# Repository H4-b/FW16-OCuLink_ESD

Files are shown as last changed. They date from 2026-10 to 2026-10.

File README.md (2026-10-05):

# OCuLink 8i Expansion Board for the Framework 16

## The schematic
rev1.1

The schematic in itself is pretty simple. You only need to connect the TX and RX PCIe lanes to the correct pins of the OCuLink connector. And then add components such as the EEPROM that the Embedded Controller (EC) on the laptop reads to configure GPIO pins and bifurcation.

A pdf version of the schematic is available [here](./imgs/schematic.pdf).

### EEPROM
As for the EEPROM, I have decided to use the same one that Framework is using in their [Dual SSD reference design](https://github.com/FrameworkComputer/ExpansionBay/tree/main/Dual%20SSD%20Reference%20Design). The `BR24G32FVT-3GE2`. The chip is marked as not recommended for new design according to Mouser, but it still seems to be in stock, although it can easily be swapped with another if required.

The EEPROM's address pins are all connected to the ground as that is the address the EC expects and by default the write protection (WP) is disabled by being connected to GND to allow writing data to it.

### Fans
For the fans I had to go with an alternative FPC header, as the one Framework uses on their boards was not available anywhere. The connector I use is slightly smaller, but still makes the connection nevertheless and the fans do spin up. I have specifically went with the [`AFC05-S04FIA-00`](https://www.lcsc.com/product-detail/C561383.html) that is available on LCSC to use with JLCPCB's assembly.

## Firmware
The firmware file is generated using [Framework's Expansion Bay tool](https://github.com/FrameworkComputer/ExpansionBayConfigurationGenerator). More info on the specific file I have been using in my testing and how I flashed it *SOON*.

## The PCB layout
rev1.1

For the layout I have went with a 4-layer board and did manage to successfully stay within JLCPCB's fabrication limits. For the production runs I have done a 1.2mm ENIG board and used the JLC04121H-7628 stackup.

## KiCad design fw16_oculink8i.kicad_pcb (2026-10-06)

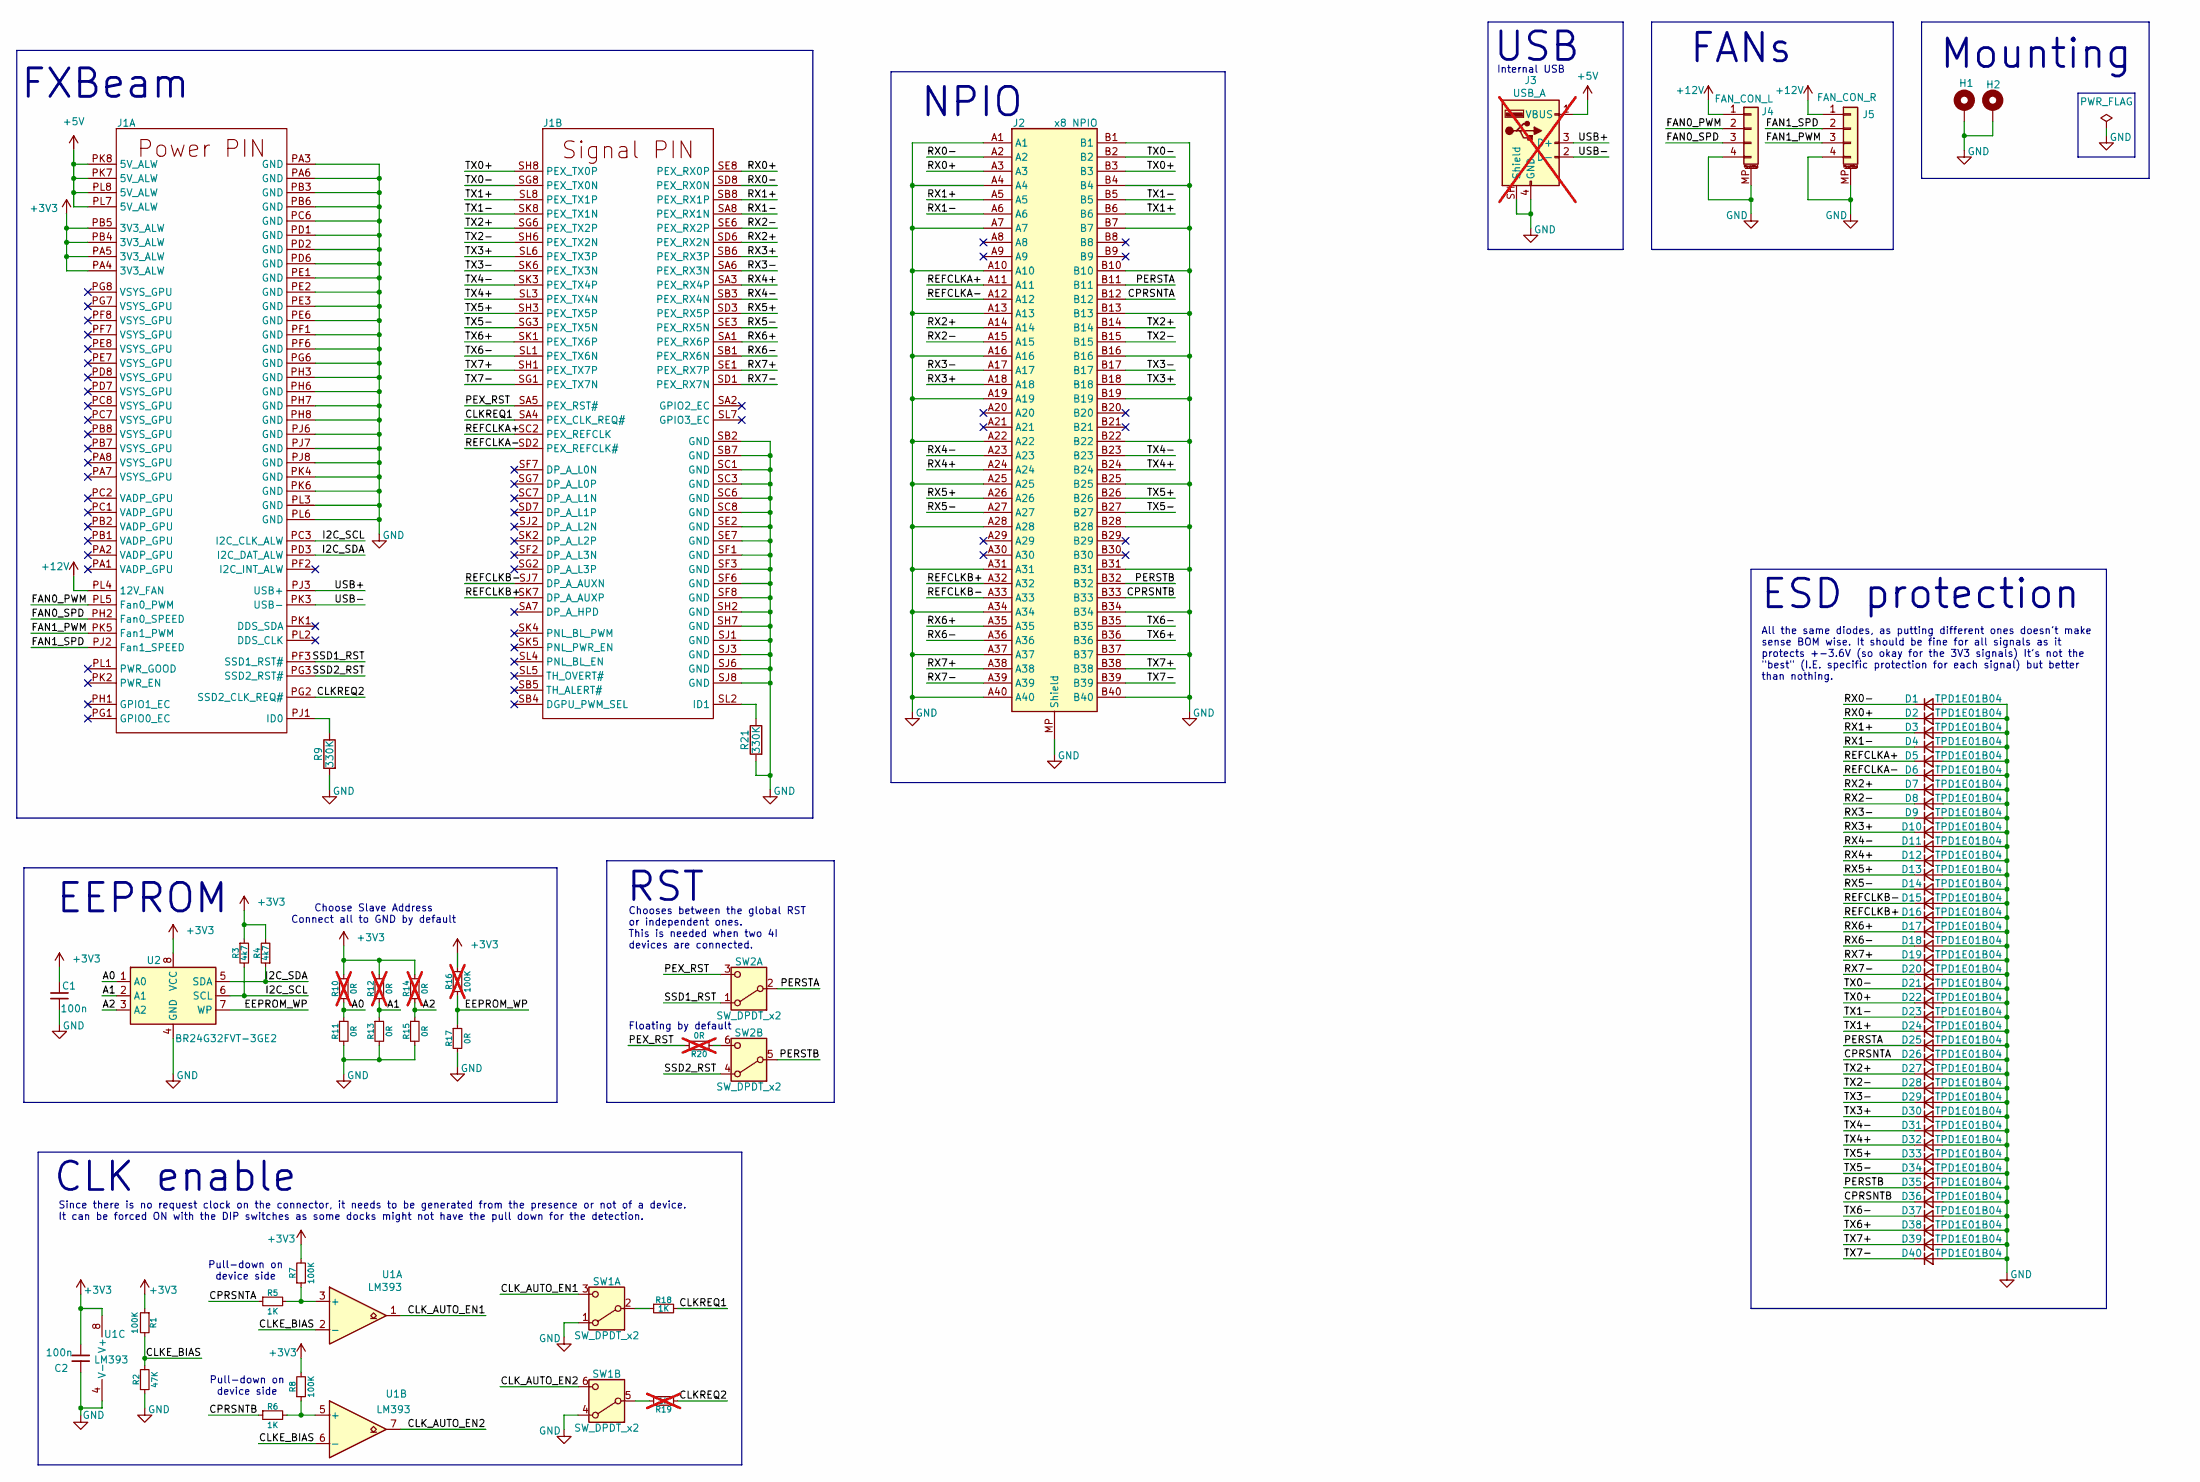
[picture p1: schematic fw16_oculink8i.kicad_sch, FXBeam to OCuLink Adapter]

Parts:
C1, C2: 100n; C_0402_1005Metric
D1, D2, D3, D4, D5, D6, D7, D8, D9, D10, D11, D12, D13, D14, D15, D16, D17, D18, D19, D20, D21, D22, D23, D24, D25, D26, D27, D28, D29, D30, D31, D32, D33, D34, D35, D36, D37, D38, D39, D40: TPD1E01B04; Texas_DPY0002A_0.6x1mm_P0.65mm
H1, H2: MountingHole_Pad; MountingHole_6.2mm_EasySolder_Cut
J1: FXBeam
J2: x8 NPIO; Nano-Pitch-173162-0132
J3: USB_A; 87583-2010BLF; not fitted
J4: FAN_CON_L; AFC58-S04FIA_4Pin
J5: FAN_CON_R; AFC58-S04FIA_4Pin
R1, R7, R8: 100K; R_0402_1005Metric
R2: 47K; R_0402_1005Metric
R3, R4: 4k7; R_0402_1005Metric; Tolerance 1%
R5, R6, R18: 1K; R_0402_1005Metric
R9, R21: 330K; R_0402_1005Metric; Tolerance 1%
R10, R12, R14, R20: 0R; R_0402_1005Metric; not fitted
R11, R13, R15, R17: 0R; R_0402_1005Metric
R16: 100K; R_0402_1005Metric; Tolerance 1%; not fitted
R19: 1K; R_0402_1005Metric; not fitted
SW1, SW2: SW_DPDT_x2; SSSS820101
U1: LM393; SOIC-8_3.9x4.9mm_P1.27mm
U2: BR24G32FVT-3GE2; TSSOP-8_4.4x3mm_P0.65mm

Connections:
+3V3: C1.1, C2.2, J1.PA4 (3V3_ALW), J1.PA5 (3V3_ALW), J1.PB4 (3V3_ALW), J1.PB5 (3V3_ALW), R1.1, R3.1, R4.2, R7.2, R8.2, R10.1, R12.1, R14.1, R16.1, U1.8 (V+), U2.8 (VCC)
+5V: J1.PK7 (5V_ALW), J1.PK8 (5V_ALW), J1.PL7 (5V_ALW), J1.PL8 (5V_ALW), J3.1 (VBUS)
+12V: J1.PL4 (12V_FAN), J4.1, J5.1
/A0: R10.2, R11.1, U2.1 (A0)
/A1: R12.2, R13.1, U2.2 (A1)
/A2: R14.2, R15.1, U2.3 (A2)
/CLKE_BIAS: R1.2, R2.2, U1.2 (-), U1.6 (-)
/CLKREQ1: J1.SA4 (PEX_CLK_REQ#), R18.2
/CLKREQ2: J1.PG2 (SSD2_CLK_REQ#), R19.2
/CLK_AUTO_EN1: SW1.3 (C), U1.1
/CLK_AUTO_EN2: SW1.6 (C), U1.7
/CPRSNTA: D26.1 (K), J2.B12, R5.1
/CPRSNTB: D36.1 (K), J2.B33, R6.1
/EEPROM_WP: R16.2, R17.1, U2.7 (WP)
/FAN0_PWM: J1.PL5 (Fan0_PWM), J4.2
/FAN0_SPD: J1.PH2 (Fan0_SPEED), J4.3
/FAN1_PWM: J1.PK5 (Fan1_PWM), J5.3
/FAN1_SPD: J1.PJ2 (Fan1_SPEED), J5.2
/I2C_SCL: J1.PC3 (I2C_CLK_ALW), R3.2, U2.6 (SCL)
/I2C_SDA: J1.PD3 (I2C_DAT_ALW), R4.1, U2.5 (SDA)
/PERSTA: D25.1 (K), J2.B11, SW2.2 (B)
/PERSTB: D35.1 (K), J2.B32, SW2.5 (B)
/PEX_RST: J1.SA5 (PEX_RST#), R20.2, SW2.3 (C)
/REFCLKA+: D5.1 (K), J1.SC2 (PEX_REFCLK), J2.A11
/REFCLKA-: D6.1 (K), J1.SD2 (PEX_REFCLK#), J2.A12
/REFCLKB+: D16.1 (K), J1.SK7 (DP_A_AUXP), J2.A32
/REFCLKB-: D15.1 (K), J1.SJ7 (DP_A_AUXN), J2.A33
/RX0+: D2.1 (K), J1.SE8 (PEX_RX0P), J2.A3
/RX0-: D1.1 (K), J1.SD8 (PEX_RX0N), J2.A2
/RX1+: D3.1 (K), J1.SB8 (PEX_RX1P), J2.A5
/RX1-: D4.1 (K), J1.SA8 (PEX_RX1N), J2.A6
/RX2+: D7.1 (K), J1.SD6 (PEX_RX2N), J2.A14
/RX2-: D8.1 (K), J1.SE6 (PEX_RX2P), J2.A15
/RX3+: D10.1 (K), J1.SB6 (PEX_RX3P), J2.A18
/RX3-: D9.1 (K), J1.SA6 (PEX_RX3N), J2.A17
/RX4+: D12.1 (K), J1.SA3 (PEX_RX4P), J2.A24
/RX4-: D11.1 (K), J1.SB3 (PEX_RX4N), J2.A23
/RX5+: D13.1 (K), J1.SD3 (PEX_RX5P), J2.A26
/RX5-: D14.1 (K), J1.SE3 (PEX_RX5N), J2.A27
/RX6+: D17.1 (K), J1.SA1 (PEX_RX6P), J2.A35
/RX6-: D18.1 (K), J1.SB1 (PEX_RX6N), J2.A36
/RX7+: D19.1 (K), J1.SE1 (PEX_RX7P), J2.A38
/RX7-: D20.1 (K), J1.SD1 (PEX_RX7N), J2.A39
/SSD1_RST: J1.PF3 (SSD1_RST#), SW2.1 (A)
/SSD2_RST: J1.PG3 (SSD2_RST#), SW2.4 (A)
/TX0+: D22.1 (K), J1.SH8 (PEX_TX0P), J2.B3
/TX0-: D21.1 (K), J1.SG8 (PEX_TX0N), J2.B2
/TX1+: D24.1 (K), J1.SL8 (PEX_TX1P), J2.B6
/TX1-: D23.1 (K), J1.SK8 (PEX_TX1N), J2.B5
/TX2+: D27.1 (K), J1.SG6 (PEX_TX2P), J2.B14
/TX2-: D28.1 (K), J1.SH6 (PEX_TX2N), J2.B15
/TX3+: D30.1 (K), J1.SL6 (PEX_TX3P), J2.B18
/TX3-: D29.1 (K), J1.SK6 (PEX_TX3N), J2.B17
/TX4+: D32.1 (K), J1.SL3 (PEX_TX4N), J2.B24
/TX4-: D31.1 (K), J1.SK3 (PEX_TX4P), J2.B23
/TX5+: D33.1 (K), J1.SH3 (PEX_TX5P), J2.B26
/TX5-: D34.1 (K), J1.SG3 (PEX_TX5N), J2.B27
/TX6+: D38.1 (K), J1.SK1 (PEX_TX6P), J2.B36
/TX6-: D37.1 (K), J1.SL1 (PEX_TX6N), J2.B35
/TX7+: D39.1 (K), J1.SH1 (PEX_TX7P), J2.B38
/TX7-: D40.1 (K), J1.SG1 (PEX_TX7N), J2.B39
/USB+: J1.PJ3 (USB+), J3.3 (D+)
/USB-: J1.PK3 (USB-), J3.2 (D-)
GND: C1.2, C2.1, D1.2 (A), D2.2 (A), D3.2 (A), D4.2 (A), D5.2 (A), D6.2 (A), D7.2 (A), D8.2 (A), D9.2 (A), D10.2 (A), D11.2 (A), D12.2 (A), D13.2 (A), D14.2 (A), D15.2 (A), D16.2 (A), D17.2 (A), D18.2 (A), D19.2 (A), D20.2 (A), D21.2 (A), D22.2 (A), D23.2 (A), D24.2 (A), D25.2 (A), D26.2 (A), D27.2 (A), D28.2 (A), D29.2 (A), D30.2 (A), D31.2 (A), D32.2 (A), D33.2 (A), D34.2 (A), D35.2 (A), D36.2 (A), D37.2 (A), D38.2 (A), D39.2 (A), D40.2 (A), H1.1 (1_1), H2.1 (1_1), J1.PA3 (GND), J1.PA6 (GND), J1.PB3 (GND), J1.PB6 (GND), J1.PC6 (GND), J1.PD1 (GND), J1.PD2 (GND), J1.PD6 (GND), J1.PE1 (GND), J1.PE2 (GND), J1.PE3 (GND), J1.PE6 (GND), J1.PF1 (GND), J1.PF6 (GND), J1.PG6 (GND), J1.PH3 (GND), J1.PH6 (GND), J1.PH7 (GND), J1.PH8 (GND), J1.PJ6 (GND), J1.PJ7 (GND), J1.PJ8 (GND), J1.PK4 (GND), J1.PK6 (GND), J1.PL3 (GND), J1.PL6 (GND), J1.SB2 (GND), J1.SB7 (GND), J1.SC1 (GND), J1.SC3 (GND), J1.SC6 (GND), J1.SC8 (GND), J1.SE2 (GND), J1.SE7 (GND), J1.SF1 (GND), J1.SF3 (GND), J1.SF6 (GND), J1.SF8 (GND), J1.SH2 (GND), J1.SH7 (GND), J1.SJ1 (GND), J1.SJ3 (GND), J1.SJ6 (GND), J1.SJ8 (GND), J2.A1, J2.A4, J2.A7, J2.A10, J2.A13, J2.A16, J2.A19, J2.A22, J2.A25, J2.A28, J2.A31, J2.A34, J2.A37, J2.A40, J2.B1, J2.B4, J2.B7, J2.B10, J2.B13, J2.B16, J2.B19, J2.B22, J2.B25, J2.B28, J2.B31, J2.B34, J2.B37, J2.B40, J2.MP (Shield), J3.4 (GND), J3.SH (Shield), J4.4, J4.MP (MountPin), J5.4, J5.MP (MountPin), R2.1, R9.2, R11.2, R13.2, R15.2, R17.2, R21.2, SW1.1 (A), SW1.4 (A), U1.4 (V-), U2.4 (GND)
unnamed: J1.PJ1 (ID0), R9.1
unnamed: J1.SL2 (ID1), R21.1
unnamed: R18.1, SW1.2 (B)
unnamed: R19.1, SW1.5 (B)
unnamed: R20.1, SW2.6 (C)
unnamed: R5.2, R7.1, U1.3 (+)
unnamed: R6.2, R8.1, U1.5 (+)

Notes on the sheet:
NPIO
CLK enable
FANs
All the same diodes, as putting different ones doesn't make sense BOM wise. It should be fine for all signals as it protects +-3.6V (so okay for the 3V3 signals) It's not the "best" (I.E. specific protection for each signal) but better than nothing.
FXBeam
USB
RST
Choose Slave Address Connect all to GND by default
Pull-down on device side
Internal USB
Floating by default
Mounting
Chooses between the global RST or independent ones. This is needed when two 4I devices are connected.
ESD protection
EEPROM
Since there is no request clock on the connector, it needs to be generated from the presence or not of a device. It can be forced ON with the DIP switches as some docks might not have the pull down for the detection.

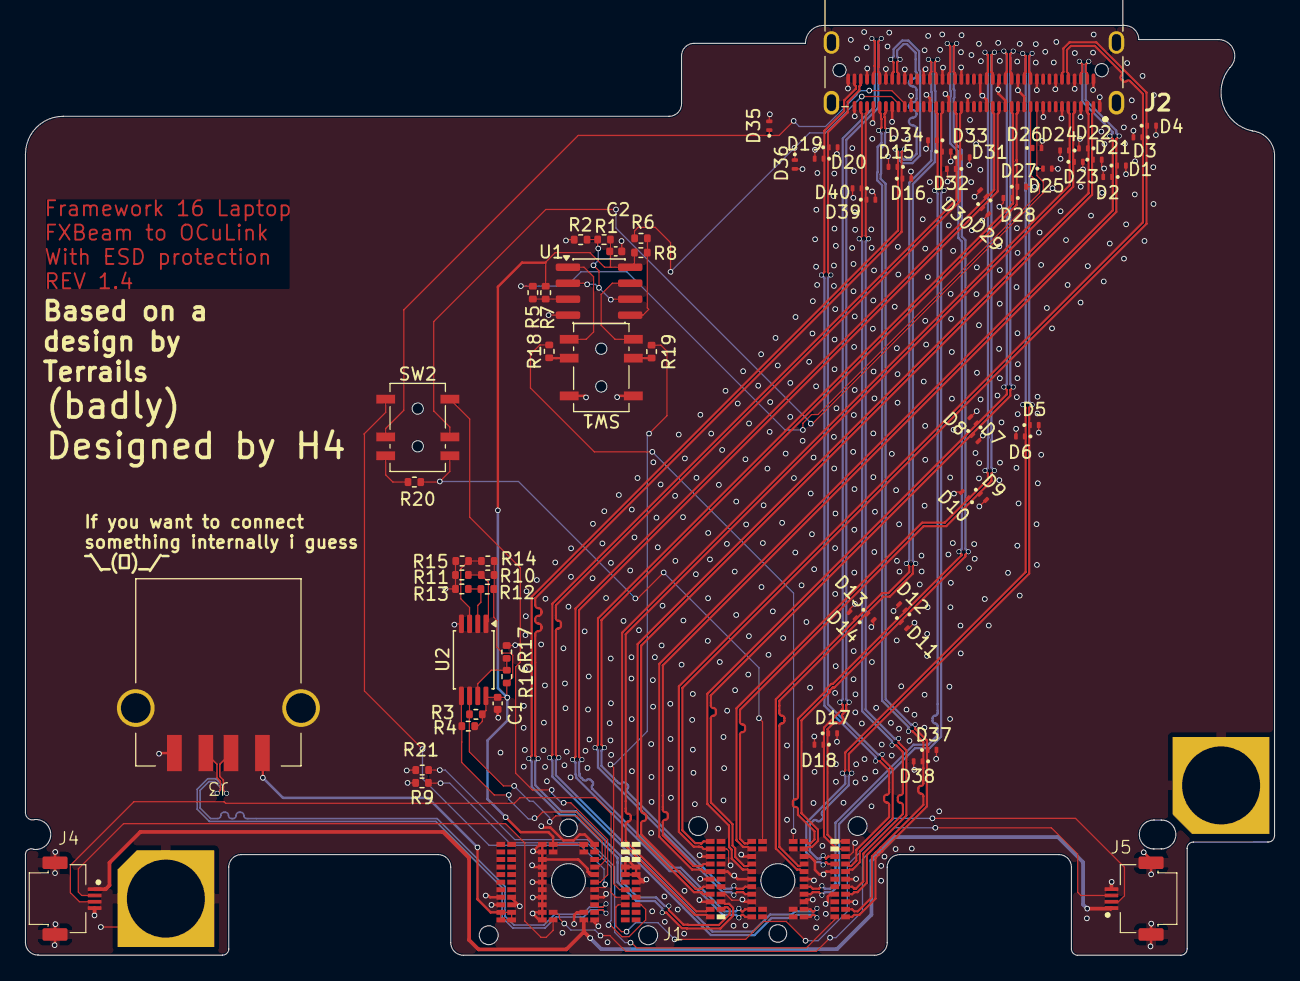
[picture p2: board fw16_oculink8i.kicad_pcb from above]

Board: 4 copper layers, 99.3 x 73.9 mm, 74 parts (0 on the bottom side), 71 nets.

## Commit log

2026-10-03 Updated files to latest kicad version (10.0.6)
    [fw16_oculink8i.kicad_pcb, fw16_oculink8i.kicad_sch]
2026-10-03 cleaned up the schematic and removed some redundant components
    A big cleanup of the schematic so that it uses power signals instead of labels.
    Some resistors where removed since they were redundant. Same with some caps and now only uses one type of switch.
    The comparator is now a dual one that consumes a bit less power too.
    [fw16_oculink8i.kicad_sch]
2026-10-03 updated FXBeam with correct input / outputs for ERC
    Updated the FXBeam symbol to have the correct input / outputs instead of unspecified for a bunch of them.
    It now passes ERC without a single error / warning.
    [fw16_oculink8i.kicad_sch]
2026-10-04 added ESD diodes
    Added the ESD diodes for the external connector.
    All the same, as it doesn't really make sense for such a low volume board to optimise costs with different low speed ones for the 3V3 signals.
    Technically it means that they are protected for 3.6V instead of 3.3V, but it should be fine.
    [fw16_oculink8i.kicad_sch]
2026-10-04 removed all tracks, vias and non position-locked connectors
    This is a cleanup before reducing the board size to 10x10cm for cheaper boards.
    [fw16_oculink8i.kicad_pcb]
2026-10-04 updated PCB shape to be smaller than 10x10cm
    All the important things should still be in their right place. The outline is well defined.
    One of the mounting hole had to be truncated, may need a small spacer to screw flat.
    [fw16_oculink8i.kicad_pcb, fw16_oculink8i.kicad_sch]
2026-10-04 routed the boards - passes ERC
    Routing done - still need to take care of the silkscreen
    [fw16_oculink8i.kicad_pcb, fw16_oculink8i.kicad_sch]
2026-10-04 placement of components Silkscreen done
    There is no error left in the ERC (other that two hole clearance violations to ignore)
    and the warnings dont matter.
    [fw16_oculink8i.kicad_pcb]
2026-10-04 added random silkscreen images
    because i'm paying for silkscreen so i'm using it!
    [fw16_oculink8i.kicad_pcb]
2026-10-05 updated routing for JLC04121H-7628 1.2mm PCBs
    Because this stackup lets you have cheaper PCBAs.
    A bit bigger traces but it should be fine.
    Passes ERC, needs a bit more GND vias scattered around.
    [fw16_oculink8i.kicad_pcb]
2026-10-05 added a whole lot of GND vias
    because high frequency so better off playing it safe and annoy JLCPCB production a bit.
    [fw16_oculink8i.kicad_pcb]
2026-10-06 updated footprint for comparator for SOIC-8
    JLCPCB has it as a standard component instead of extended, so 3 bucks cheaper (yay)
    [fw16_oculink8i.kicad_pcb, fw16_oculink8i.kicad_sch]
